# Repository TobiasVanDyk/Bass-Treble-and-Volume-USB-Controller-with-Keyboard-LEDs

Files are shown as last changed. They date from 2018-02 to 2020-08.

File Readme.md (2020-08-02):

# Bass, Treble, and Volume USB Controller with Keyboard LED

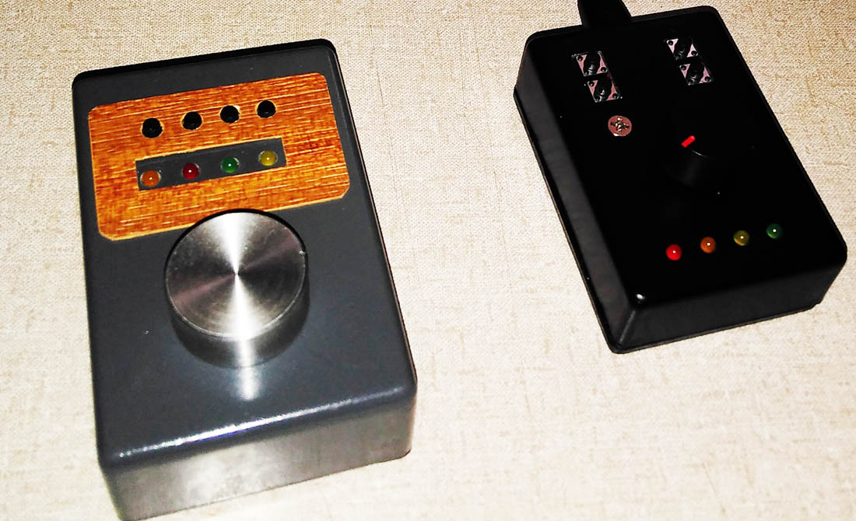
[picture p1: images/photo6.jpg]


For more details please see the [**Instructables project**](https://www.instructables.com/id/Bass-Treble-and-Volume-USB-Controller-With-Keyboar/)

I have a Creative SoundBlaster Audigy in my main desktop computer and I needed a way to quickly adjust the bass and treble settings (as well as the volume) when listening to audio or video media. I have adapted the code from two sources given in the code-listing, and also in the links at the end, which makes use of an Arduino Micro by the Arduino organisation, or any other ATmega32u4, as a USB Human Interface Device by using the Nico Hood HID-Project libraries. I also use a wireless keyboard which only shows the state of the Caps-lock, Num-lock and Scroll-lock keys for a short time to increase its battery life. I therefore also included three LED's which show the status of these three keyboard functions. Because the Micro can be easily reprogrammed even after putting it into an enclosure through the USB port, you can adapt the code to suit the characteristics of your own sound device and keyboard by substituting the media identification used in the code with your own selection. There is a vast list of all the functions that you can use available at the Nico Hood HID Github website - examine the file named ConsumerAPI.h for all the other HID functions. 

### Parts List

* Arduino Micro or any other ATmega32u4 based Arduino board such as the Sparkfun Pro Micro or the DFRobot Beetle. The Leonardo can be also used but it is a very big board compared to the micro. 
* 5 LEDs of different colour 
* 5 x 470 ohm resistors 
* 4 x pushbutton switches 
* Rotary encoder with A B C and a switch connection 
* Small enclosure, knob, strip board, connection wire etc. 

### Construction

Details are given in the photos, schematic and the Fritzing stripboard layouts. I used two smaller strip boards - one to house 4 LEDs and the four switches, and the other for a blue volume level direction indicator LED, and a larger stripboard for the micro and the rotary encoder. They are connected with a 9-way ribbon cable.

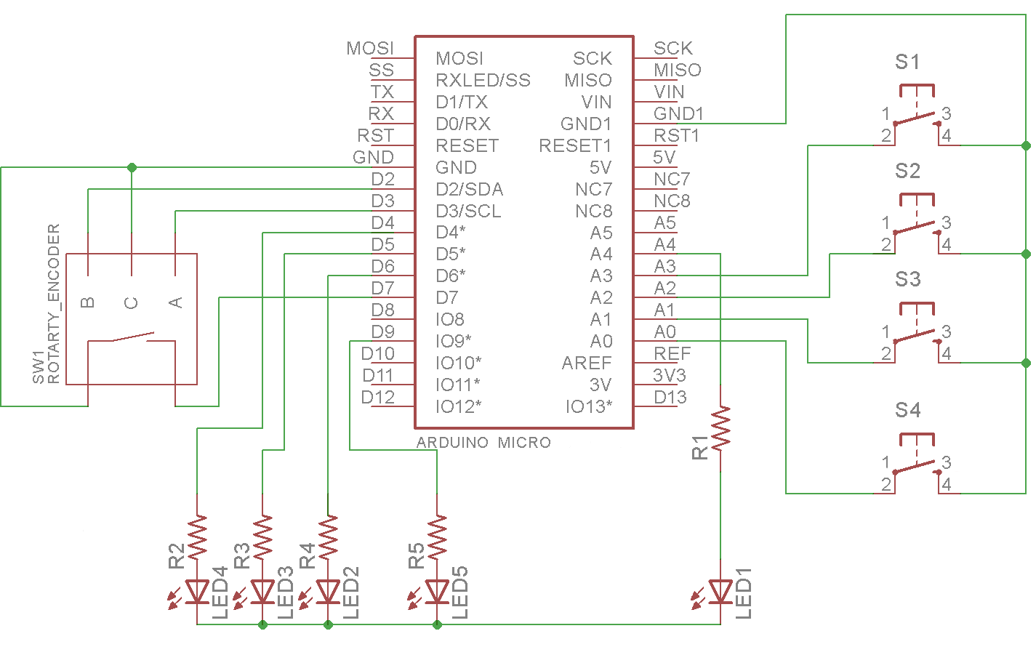
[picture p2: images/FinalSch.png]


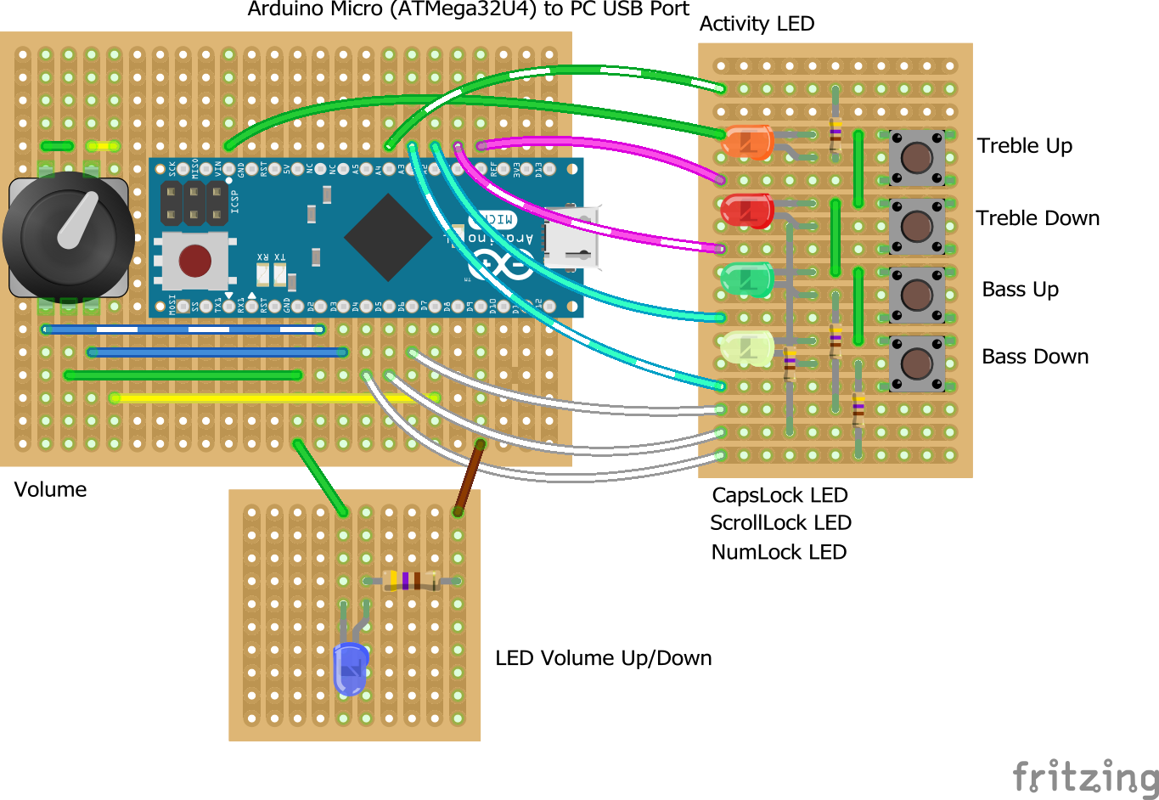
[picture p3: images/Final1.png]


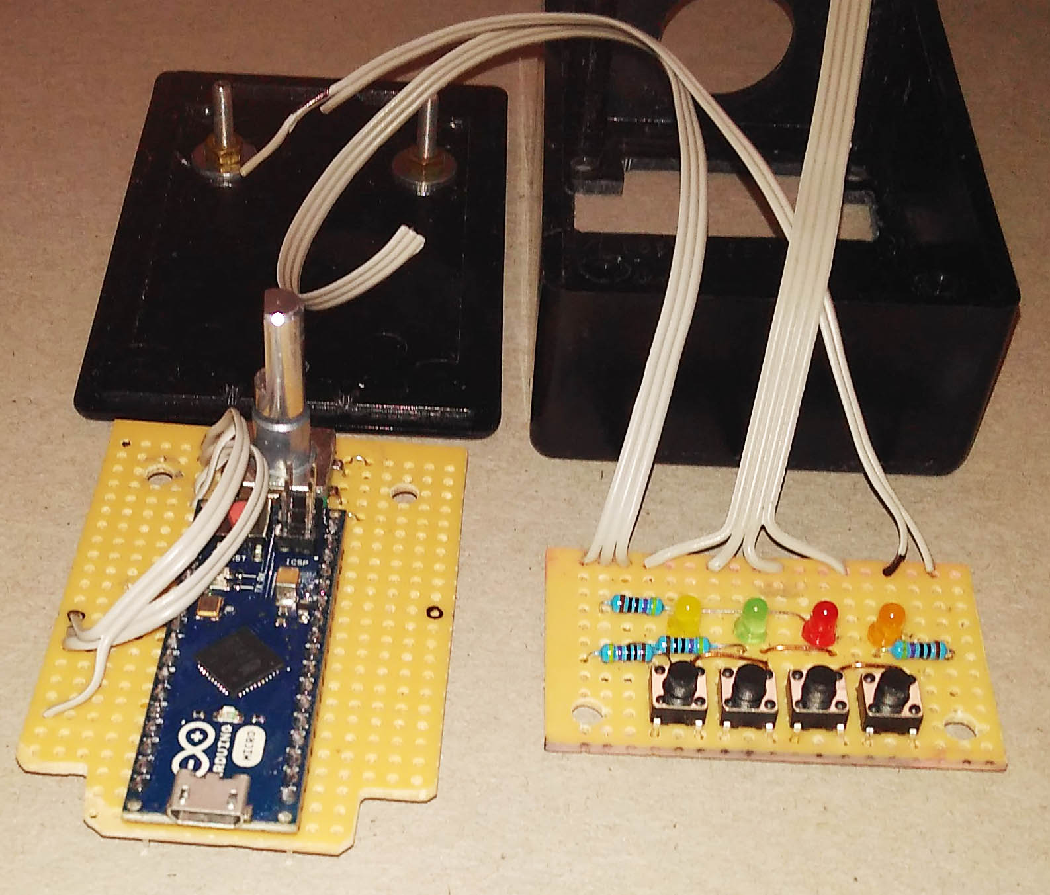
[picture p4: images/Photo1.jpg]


### Software
As mentioned this USB Volume, Bass, and Treble Control use a rotary encoder as the volume control with a mute/unmute switch, and the Bass and Treble controlled by four Up and Down buttons. It also has PC Keyboard LED indicators namely Caps-lock, Scroll-lock, and Num-lock. It uses an Arduino Micro (or other ATmega32u4-based) MCU and the code is based on the transition states ISR roto_sm.ino by boolrules at the Arduino forum, which gives clearly differentiated up and down triggers. The code is also based on pleriche's USB Volume Control and Caps Lock LED instructable. It requires the Nico Hood HID-Project library at github: download the library as a zip file and extract it, then copy the folder to your Arduino library folder underneath your documents folder. Because the Micro can be easily reprogrammed via its USB port, you can adapt the code to suit the characteristics of your own sound device and keyboard by substituting the media instruction used in the code with your own selection. There is a vast list of all the functions that you can use available at the Nico Hood HID Github website - examine the file named ConsumerAPI.h for all the other HID functions which can include system functions such as sleep or reboot key etc. I have included photos of the construction as it progressed. Source code is in Final.ino.

### Adding Bass and Treble Rotary Controls

It is possible to replace the four pushbuttons that control the bass and treble with two rotary controls. Schematic2 gives the details and the source code is in Sketch2.ino. The two pushbuttons on each control are used to give a bass boost and treble boost respectively.

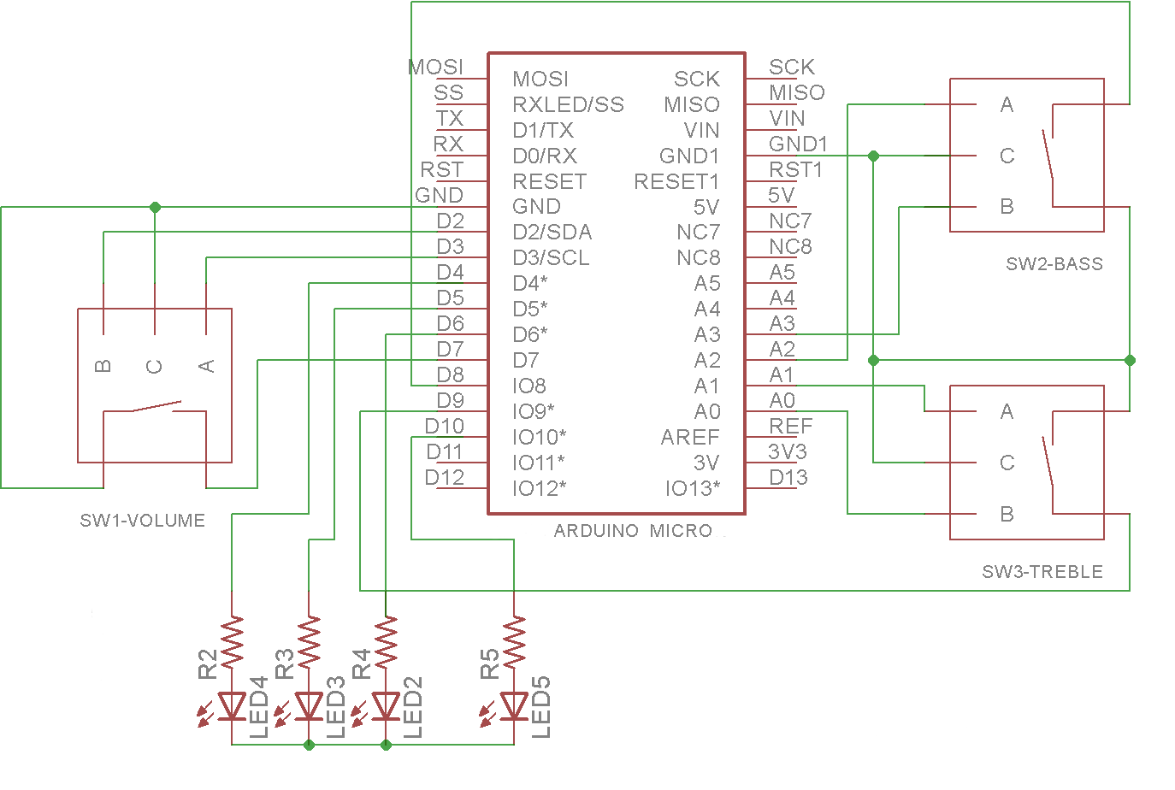
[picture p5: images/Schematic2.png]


### Use a Sparkfun Pro Micro and DFRobot Beetle for a Smaller Case

You can use the smaller version of the Arduino Micro namely the Sparkfun Pro Micro to make a smaller enclosure for the Bass Treble Volume and Keyboard LED USB Controller. Photo5 and Photo6 gives the details of the build and you can use Sketch3.ino for the Pro Micro.

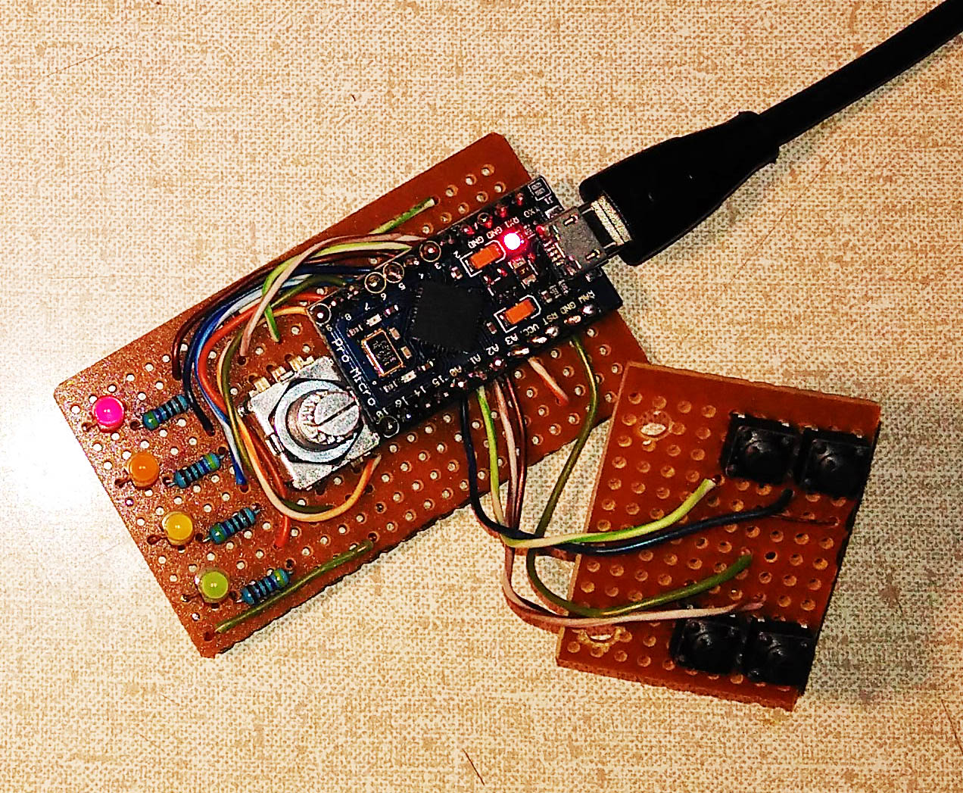
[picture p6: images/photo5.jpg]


A recent addition, and even smaller MCU board that can also be used, is the **DFRobot Beetle** https://www.dfrobot.com/wiki/index.php/Beetle_SKU:DFR0282. You can use Beetle.ino for the Arduino sketch.

<p align="left">
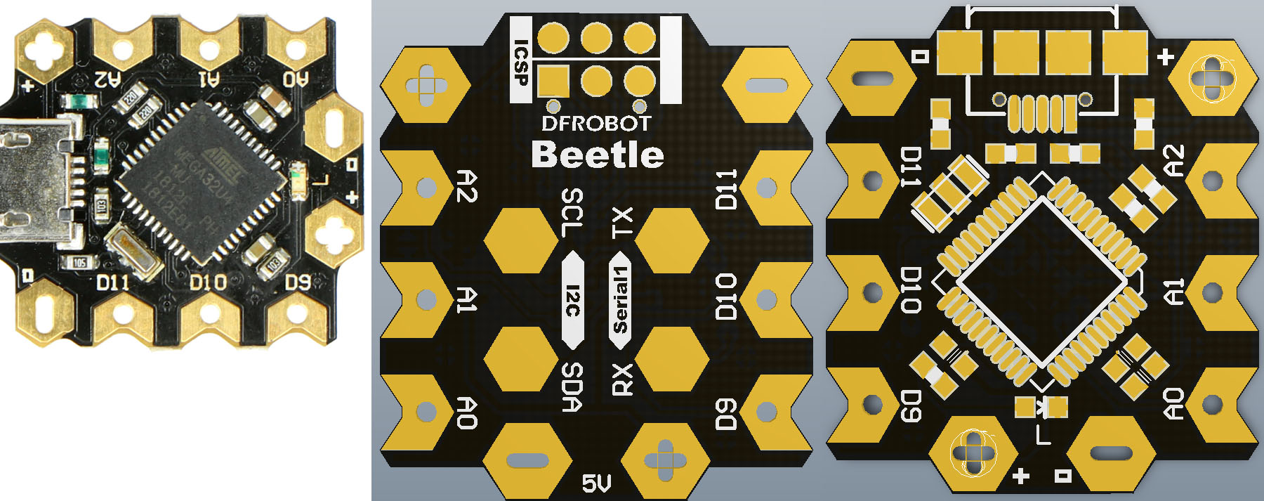
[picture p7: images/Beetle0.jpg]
  
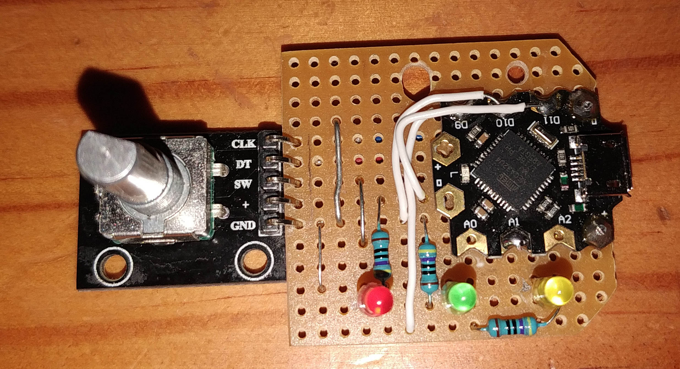
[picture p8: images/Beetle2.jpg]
  
</p>

<p align="left">
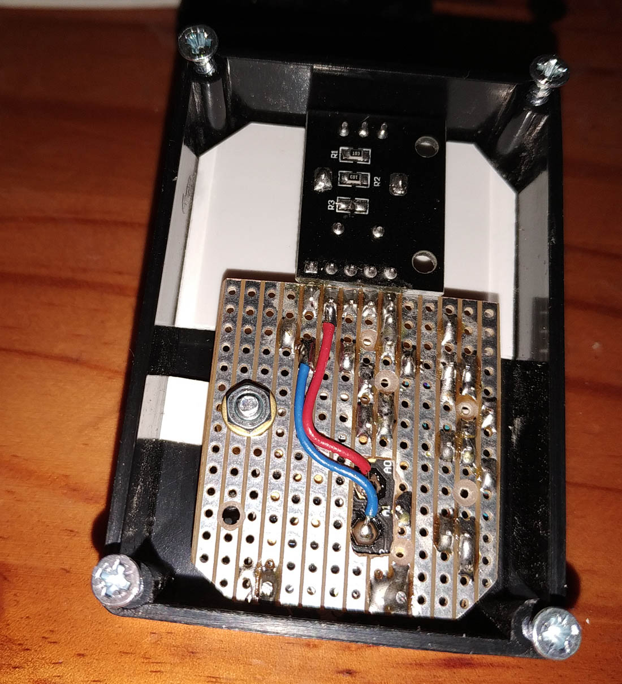
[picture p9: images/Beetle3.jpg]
  
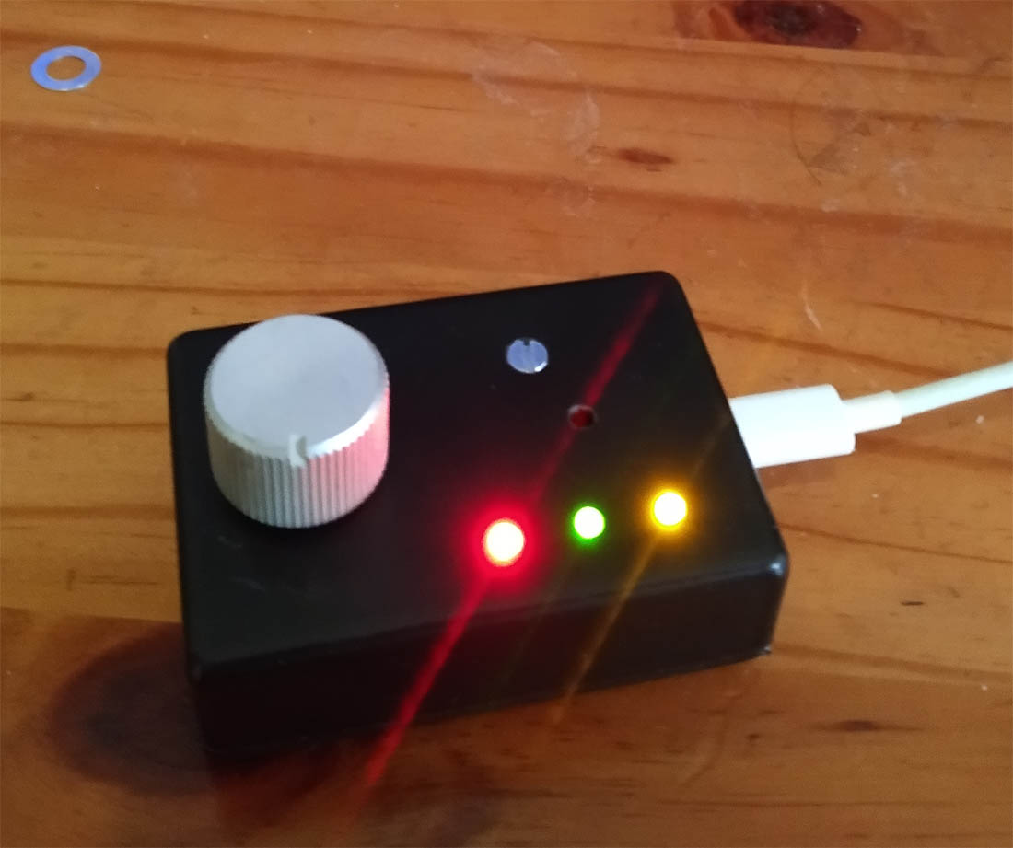
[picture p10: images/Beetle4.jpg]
  
</p>

### Other Links

* Arduino Micro https://store.arduino.cc/arduino-micro
* State machine ISR roto_sm.ino by boolrules https://forum.arduino.cc/index.php?topic=242356.15
* P LeRiche USB Volume Control and Caps Lock LED https://www.instructables.com/id/USB-Volume-Control-and-Caps-Lock-LED-Simple-Cheap-/
* Nico Hood HID-Project Github library https://github.com/NicoHood/HID/wiki

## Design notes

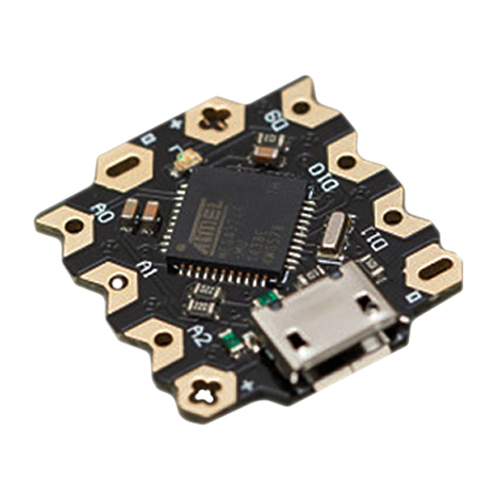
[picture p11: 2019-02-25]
images/beetle.jpg

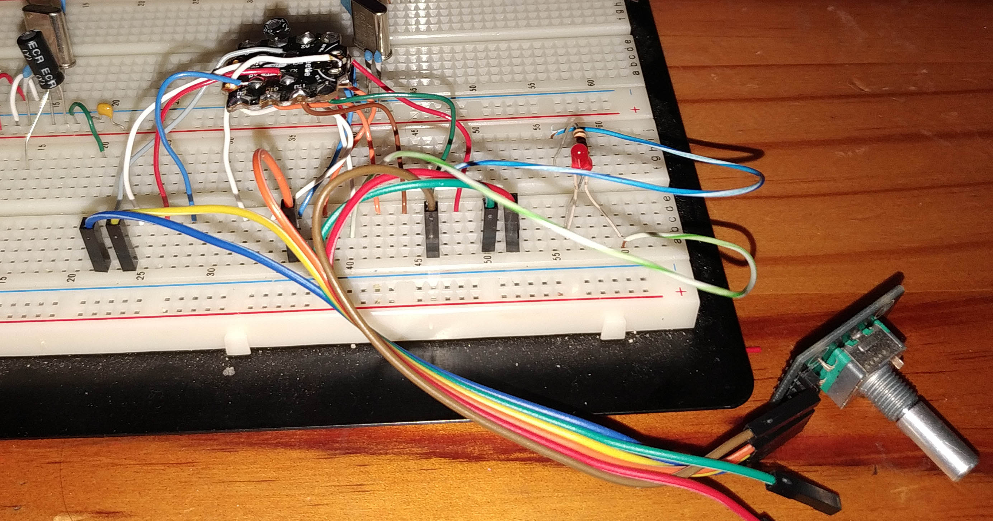
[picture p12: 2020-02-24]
images/Beetle5.jpg

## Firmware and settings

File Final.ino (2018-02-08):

/////////////////////////////////////////////////////////////////////////////////////////
// PC USB Volume Bass Treble Control:
// Volume control by rotary encoder
// Bass and Treble controlled by Up and Down buttons
//
// PC Keyboard LED indicators for wireless keyboards:
// Caps-lock Scroll-lock Num-lock
//
// Requires Arduino Micro (or other ATmega32u4-based) MCU
//
// Code based on valid transition states ISR roto_sm.ino by boolrules at:
// https://forum.arduino.cc/index.php?topic=242356.15
// This seems to give clearly differentiated up and down triggers
//
// Code also based on p_leriche USB Volume Control and Caps Lock LED:
// https://www.instructables.com/id/USB-Volume-Control-and-Caps-Lock-LED-Simple-Cheap-/
//
// Requires the Nico Hood HID-Project library:
// https://github.com/NicoHood/HID/wiki
//
// Code sources above adapted by Tobias van Dyk February 2018
//
/////////////////////////////////////////////////////////////////////////////////////////

#include <HID.h>
#include <HID-Project.h>  

#define DIR_NONE 0x00           // No complete step yet.
#define DIR_CW   0x10           // Clockwise step.
#define DIR_CCW  0x20           // Anti-clockwise step.

unsigned int state;
int count = 0;         // count each indent
int old_count = 0;     // check for count changed

/*
 * The below state table has, for each state (row), the new state
 * to set based on the next encoder output. From left to right in,
 * the table, the encoder outputs are 00, 01, 10, 11, and the value
 * in that position is the new state to set.
 */

// State definitions state table (emits a code at 00 only)
// states are: (NAB) N = 0: clockwise;  N = 1: counterclockwiswe
#define R_START     0x3
#define R_CW_BEGIN  0x1
#define R_CW_NEXT   0x0
#define R_CW_FINAL  0x2
#define R_CCW_BEGIN 0x6
#define R_CCW_NEXT  0x4
#define R_CCW_FINAL 0x5

const unsigned char ttable[8][4] = {
    {R_CW_NEXT,  R_CW_BEGIN,  R_CW_FINAL,  R_START},                // R_CW_NEXT
    {R_CW_NEXT,  R_CW_BEGIN,  R_CW_BEGIN,  R_START},                // R_CW_BEGIN
    {R_CW_NEXT,  R_CW_FINAL,  R_CW_FINAL,  R_START | DIR_CW},       // R_CW_FINAL
    {R_START,    R_CW_BEGIN,  R_CCW_BEGIN, R_START},                // R_START
    {R_CCW_NEXT, R_CCW_FINAL, R_CCW_BEGIN, R_START},                // R_CCW_NEXT
    {R_CCW_NEXT, R_CCW_FINAL, R_CCW_FINAL, R_START | DIR_CCW},      // R_CCW_FINAL
    {R_CCW_NEXT, R_CCW_BEGIN, R_CCW_BEGIN, R_START},                // R_CCW_BEGIN
    {R_START,    R_START,     R_START,     R_START}                 // ILLEGAL
};

// Define Arduino pin numbers for buttons and LEDs
#define NumLockLED 4
#define CapsLockLED 5 
#define ScrLockLED 6 

#define ActivityLED A4      // A4 Show Activity
#define VolumeLED 9         // PWM 9 Vol Level

#define RotaryA 2 
#define RotaryB 3 
#define RotaryC 7

#define btnBassUp A0        // A0 Bass Increase
#define btnBassDwn A1       // A1 Bass Decrease
#define btnTrebleUp A2      // A2 Treble Increase
#define btnTrebleDwn A3     // A3 Treble Decrease

boolean AnyBtnPress = false;
byte n = 255;
byte VolumeLevel = 16;

////////////////////////////////////////////////////////
// Valid transition states ISR roto_sm.ino by boolrules
////////////////////////////////////////////////////////
void AB_isr( ) 
{
    // Grab state of input pins.
    unsigned char pinstate = (digitalRead( RotaryA ) << 1) | digitalRead( RotaryB );

    // Determine new state from the pins and state table.
    state = ttable[state & 0x07][pinstate];

    if( state & DIR_CW )    
      { count++;                            // count up for clockwise
        Consumer.write(MEDIA_VOL_UP);
        VolumeLevel = 255;
      }
    if( state & DIR_CCW )   
      { count--;                           // count down for counterclockwise
        Consumer.write(MEDIA_VOL_DOWN);
        VolumeLevel = 32; 
      }
    
}

//////////////////////////////////////////////////
//
//////////////////////////////////////////////////
void setup() 
{
  pinMode (btnTrebleDwn, INPUT_PULLUP);
  pinMode (btnTrebleUp, INPUT_PULLUP);
  pinMode (btnBassDwn, INPUT_PULLUP); 
  pinMode (btnBassUp, INPUT_PULLUP); 

  pinMode (ActivityLED, OUTPUT);
  pinMode (VolumeLED, OUTPUT);

  pinMode(RotaryA, INPUT_PULLUP);
  pinMode(RotaryB, INPUT_PULLUP);
  pinMode(RotaryC, INPUT_PULLUP);

  pinMode(CapsLockLED, OUTPUT);
  pinMode(ScrLockLED, OUTPUT);
  pinMode(NumLockLED, OUTPUT);

  AnyBtnPress = false;

  state = (digitalRead( RotaryA ) << 1) | digitalRead( RotaryB );     // Initialise state.
  old_count = 0;

  attachInterrupt( 0, AB_isr, CHANGE );   // pin-change interrupts: 
  attachInterrupt( 1, AB_isr, CHANGE );

  Consumer.begin();          // Start Media Keys
  BootKeyboard.begin();      // Start Keybrd LEds
  //  System.begin();        // For System functions
  //  Gamepad.begin();       // For gamepad functions
  //  Mouse.begin();         // For mouse functions
  //  AbsoluteMouse.begin(); // For the Absolute Mouse

  // Flash the LEDs just to show we're in business
  digitalWrite(CapsLockLED, HIGH); delay(100);
  digitalWrite(ScrLockLED, HIGH); delay(100);
  digitalWrite(NumLockLED, HIGH); delay(100);
  digitalWrite(ActivityLED, HIGH); delay(100);
  digitalWrite(VolumeLED, HIGH); delay(100);
  digitalWrite(CapsLockLED, LOW); delay(100);
  digitalWrite(ScrLockLED, LOW); delay(100);
  digitalWrite(NumLockLED, LOW); delay(100);
  digitalWrite(ActivityLED, LOW); delay(100);
  digitalWrite(VolumeLED, LOW); delay(100);

}

//////////////////////////////////////////////////
//
//////////////////////////////////////////////////
void loop() 
{
    //check if the buttons are being pressed
    chkBtn(); if (AnyBtnPress) readBtn(); 

    if (n == 0)
       { if (BootKeyboard.getLeds() & LED_CAPS_LOCK) digitalWrite(CapsLockLED, HIGH);  // Capslock
                                                else digitalWrite(CapsLockLED, LOW);
         if (BootKeyboard.getLeds() & LED_SCROLL_LOCK) digitalWrite(ScrLockLED, HIGH); // Scrolllock
                                                  else digitalWrite(ScrLockLED, LOW);
         if (BootKeyboard.getLeds() & LED_NUM_LOCK) digitalWrite(NumLockLED, HIGH);
                                              else  digitalWrite(NumLockLED, LOW);
         //check if the buttons are being pressed
         chkBtn(); if (AnyBtnPress) readBtn(); 
       }
    
    analogWrite (VolumeLED, VolumeLevel);
    n--;
}

////////////////////////////////////////////////////////////
//
////////////////////////////////////////////////////////////
void chkBtn()
{
  int btnTrebleDwnState = digitalRead(btnTrebleDwn);
  int btnTrebleUpState = digitalRead(btnTrebleUp);
  int btnBassDwnState  = digitalRead(btnBassDwn);
  int btnBassUpState  = digitalRead(btnBassUp);
  int btnRotary = digitalRead(RotaryC);

  AnyBtnPress = false;
  if (!btnTrebleDwnState||!btnTrebleUpState||!btnBassDwnState||!btnBassUpState||!btnRotary)  AnyBtnPress = true;
}
////////////////////////////////////////////////////////////
//
////////////////////////////////////////////////////////////
void readBtn()
{ 
  //Check if buttons are pressed
  int btnTrebleDwnState = digitalRead(btnTrebleDwn);
  int btnTrebleUpState = digitalRead(btnTrebleUp);
  int btnBassDwnState  = digitalRead(btnBassDwn);
  int btnBassUpState  = digitalRead(btnBassUp);
  int btnRotary = digitalRead(RotaryC);

  if (!btnTrebleUpState) 
     { digitalWrite (ActivityLED, HIGH);
       delay(100) ;
       Consumer.write(HID_CONSUMER_TREBLE_INCREMENT);
     }
  else
  if (!btnTrebleDwnState)  
     { digitalWrite (ActivityLED, HIGH);
       delay(100) ;
       Consumer.write(HID_CONSUMER_TREBLE_DECREMENT);
     }

  if (!btnBassUpState) 
     { digitalWrite (ActivityLED, HIGH);
       delay(100) ;
       Consumer.write(HID_CONSUMER_BASS_INCREMENT);
     }
  else
  if (!btnBassDwnState)  
     { digitalWrite (ActivityLED, HIGH);
       delay(100) ;
       Consumer.write(HID_CONSUMER_BASS_DECREMENT);
     }

  if (!btnRotary)  
     { digitalWrite (ActivityLED, HIGH);
       delay(100) ;
       Consumer.write(MEDIA_VOL_MUTE);
       delay(100) ;
     }

  delay(100);
  digitalWrite (ActivityLED, LOW);
     
}
